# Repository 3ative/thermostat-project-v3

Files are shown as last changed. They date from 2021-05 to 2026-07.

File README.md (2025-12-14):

# ESPHome Thermostat Project V3

Use the "**Code**" button above "**Download ZIP**" to get everything you need.



*Un-ZIP and copy the "**_fonts**" and "**_icons**" folders to your "esphome" folder BEFORE you copy/paste the yaml in to ESPHome*

* 3D Printer files provided are as seen in the tutorial and can be used as a base model for your own 'Front Plate' mounting solutions.

## 2025.2.0 Breaking Change ALERT!!!: (See Comments in the code)
* "Platform": Both the ``esphome:`` and "board" have changed - Now Fixed.
* Changes to how Images are displayed has also beed changed  - Now Fixed.
* Icons and GIFs needed colours inverted  - Now Fixed.

## Please Be Aware:
* Depending on the supplier, SOME OLED displays have the VCC & GND (0v) pins reversed - Be sure to check and adjust your build accordingly.

# Watch the full tutorial here: https://youtu.be/RorDXsYIrnQ

## I have also made a custom PCB for this project. Grab one here: https://www.ebay.co.uk/itm/203570959081




---

<div align="center">

### 💖 Support This Project

Found this useful? Want to say thanks and fuel future creations?

**Your support keeps the creativity flowing!** 🍺✨

<table>
  <tr>
    <td align="center">
      <a href="https://www.buymeacoffee.com/3ative">
        
        <br/>
        <b>☕ Buy me a Coffee</b>
      </a>
    </td>
    <td align="center">
      <a href="https://www.patreon.com/3ative">
        
        <br/>
        <b>💖 Join on Patreon</b>
      </a>
    </td>
  </tr>
</table>

**Every contribution helps bring more awesome projects to life!** 🚀

</div>

---

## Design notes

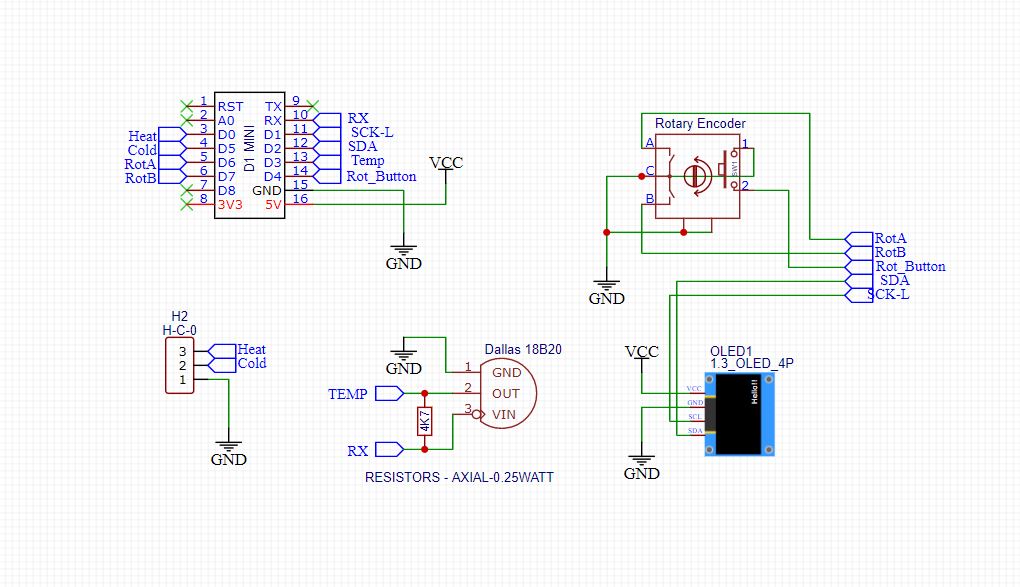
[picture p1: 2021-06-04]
schematic_revised.JPG

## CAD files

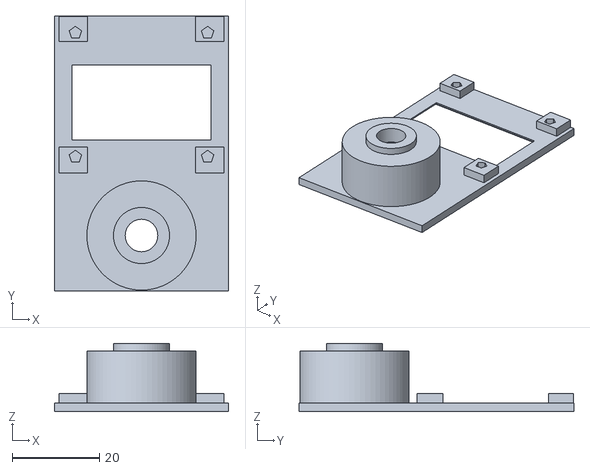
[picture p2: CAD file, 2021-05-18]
3d_printer_files/thermostat_front_plate.stl
40.0 x 63.2 x 15.7

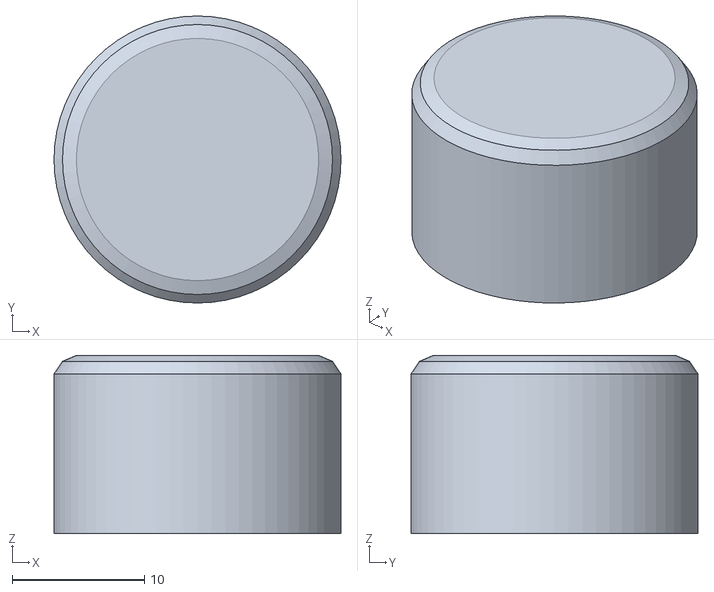
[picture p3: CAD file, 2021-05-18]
3d_printer_files/thermostat_knob.stl
21.7 x 21.7 x 13.5

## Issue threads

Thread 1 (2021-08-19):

Update esphome2021.8.0

twty, 2021-08-19:
Hi,
Esphome 2021.8.0, just replace the hystersis whit 4 new function ''cool_deadband, cool_overrun, heat_deadband and heat_overrun.''
I think you have to update yaml file acording to this change .
regards

3ative, 2021-08-20:
@twty  Thanks for the info. 👍
Please take a look at the YAML code, I updated it. Tested and working here'
Lemma know how you get on.

Closed 2022-02-06.

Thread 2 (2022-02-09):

Thermostat YAML & indication issue

newbie22-guy, 2022-02-09:
I have encountered an issue when trying to compile this project and hope you can assist.

When I used the code supplied I get the following error messages
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

The first issue (lines 72, 73, 76, 77 &78 I resolved with the addition of a # as seen in lines 74 & 75.

The error for line 177 [set_contrast] has been significantly more difficult, and I have not been able to resolve this.
If I move the indentation in or out by  x1 column the indentation error does not repeat but the colon then becomes an issue as the YAML sees it as a mapping value.

I have managed to temporarily bypass this issue, with the deletion of the set_contrast: line (and the associated lines in the YAML).
This allowed me to achieve an upload and some degree of success with the thermostat.

Upon upload I have input the Dallas sensor address, and uncommoned the specified lines as per YouTube tutorial

Within homeassistant I have functionality of both setpoints via the rotary encoder.
This is mirrored on the OLED display, with the graphics.
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

Unfortunately I have no temperature indication either on the OLED or on homeassistant.

3ative, 2022-02-09:
Your line (177) should be this "contrast: 0.4"

As for the others, I see your line numbers are different from my original code. Please post me your full code and I'll take a look.
FYI - To format the code you post, start the block of text with:
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

and end it with:
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

- Those are 'Back checks' and are on the key under the ESc key. :)

newbie22-guy, 2022-02-09:
Thanks for your response.
The coding (from my initial query) I suspect was an old revision, as I re-downloaded the files today and compared them and noted some alterations.
I have now used the latest available YAML.

Based on your reply I now have the original code (now line 196).

This initially gave an error requesting an indentation check, By revising to as below the indentation has been satisfied, but the colon is still posing an issue, I have attached the specific  fault/ issue this highlights.

```yaml
esphome:
  name: thermostat_kitchen
  platform: ESP8266
  board: d1_mini
  on_boot:
    then:
      - lambda: "id(oled_contrast).publish_state(0.4);"
      - switch.turn_off: dallas_power
      - delay: 25s
      - switch.turn_on: dallas_power

substitutions:
  room: Kitchen # Room Name
  entity_heater: input_boolean.tut_thermo_fire_lr
  entity_cooler: input_boolean.tut_thermo_cool_lr
  default_low: "20.0"
  default_hi: "28.0"

wifi:
  ssid: "Deliberately Removed"
  password: "Deliberately Removed"

logger:
  logs:
    climate: none
    sensor: none
    dallas.sensor: none

api:
ota:

i2c:

switch:
  - platform: gpio
    id: dallas_power
    pin:
      number: GPIO03

  - platform: template
    id: heat_cool

    optimistic: true
  - platform: gpio
    id: relay_heater
    pin: D0
    inverted: true
  - platform: gpio
    id: relay_cooler
    pin: D5
    inverted: true
  - platform: template
    id: brightness
    optimistic: true

binary_sensor:
  - platform: template
    id: fire
  - platform: template
    id: cool

  - platform: gpio
    id: button
    pin:
      number: D4
      inverted: true
    on_press:
      then:
        - switch.toggle: heat_cool
    on_click:
      - min_length: 1000ms
        max_length: 20000ms
        then:
          - switch.toggle: brightness

dallas:
  pin: D3
  update_interval: 3s

climate:
  - platform: thermostat
    min_cooling_off_time: 0s
    min_cooling_run_time: 0s
    # min_fanning_off_time: 0s
    # min_fanning_run_time: 0s
    min_heating_off_time: 0s
    min_heating_run_time: 0s
    min_idle_time: 0s
    visual:
      min_temperature: 15 °C
      max_temperature: 30 °C
    name: "${room} Thermostat"
    id: this_thermostat
    sensor: internal_temperature

    default_target_temperature_low: ${default_low}
    default_target_temperature_high: ${default_hi}

    cool_action:
      - switch.turn_on: relay_cooler
      - lambda: id(cool).publish_state(true);
      - homeassistant.service:
          service: homeassistant.turn_on
          data:
            entity_id: ${entity_cooler}

    heat_action:
      - switch.turn_on: relay_heater
      - lambda: id(fire).publish_state(true);
      - homeassistant.service:
          service: homeassistant.turn_on
          data:
            entity_id: ${entity_heater}

    idle_action:
      - switch.turn_off: relay_cooler
      - switch.turn_off: relay_heater
      - lambda: id(cool).publish_state(false);
      - lambda: id(fire).publish_state(false);
      - homeassistant.service:
          service: homeassistant.turn_off
          data:
            entity_id: ${entity_cooler}
      - homeassistant.service:
          service: homeassistant.turn_off
          data:
            entity_id: ${entity_heater}

sensor:
  - platform: template
    id: oled_contrast

  - platform: dallas
    id: internal_temperature
    address: 0x28ff6401be7b6410

  - platform: rotary_encoder
    id: encoder
    pin_a:
      number: D6
      mode: INPUT_PULLUP
    pin_b:
      number: D7
      mode: INPUT_PULLUP
    on_clockwise:
      - if:
          condition:
            switch.is_on: brightness
          then:
            - sensor.template.publish:
                id: oled_contrast
                state: !lambda "return id(oled_contrast).state + 0.01;"
            - lambda: |-
                id(oled1).set_contrast( id(oled_contrast).state );
          else:
            - if:
                condition:
                  switch.is_on: heat_cool
                then:
                  - climate.control:
                      id: this_thermostat
                      target_temperature_high: !lambda "return id(this_thermostat).target_temperature_high + 0.5;"
                else:
                  - climate.control:
                      id: this_thermostat
                      target_temperature_low: !lambda "return id(this_thermostat).target_temperature_low + 0.5;"

    on_anticlockwise:
      then:
        - if:
            condition:
              switch.is_on: brightness
            then:
              - sensor.template.publish:
                  id: oled_contrast
                  state: !lambda "return id(oled_contrast).state - 0.01;"
              - lambda: |-
                  id(oled1).set_contrast( id(oled_contrast).state);
            else:
              - if:
                  condition:
                    switch.is_on: heat_cool
                  then:
                    - climate.control:
                        id: this_thermostat
                        target_temperature_high: !lambda "return id(this_thermostat).target_temperature_high - 0.5;"
                  else:
                    - climate.control:
                        id: this_thermostat
                        target_temperature_low: !lambda "return id(this_thermostat).target_temperature_low - 0.5;"
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
3ative, 2022-02-11:
Try this,
Wire the Dallas sensor, on its's own to a D1 Mini and flash only with the code example here
https://esphome.io/components/sensor/dallas.html

If it still doesn't work, I guess it's your sensors.

newbie22-guy, 2022-02-11:
I was beginning to suspect likewise, but I was dubious that I would have so many faulty sensors.

Initially I built the DS_Fake_Tester by electrical-pro (https://github.com/electrical-pro/Ds_Fake_Tester)
This proved to be quite encouraging as all the sensors indicated as being genuine, and displayed readings.

I've had another play with these this morning.
Using the guide below
https://everythingsmarthome.co.uk/howto/building-a-temperature-sensors-for-home-assistant-wemos-d1-mini-with-ds18b20-build-guide/

Initially I built this up on breadboard for simplicity of substituting sensors & D1's.
I have successfully managed to gain temperature readings from multiple sensors.
I have also managed this with a number of D1 mini's.

I amended the code from the example to increase the refresh rate to 3 sec, and alternated the GPIO pin between pin 3 & 4 (to confirm no issue with either pin)
Both worked as expected and provided updates every 3 secs, with no issue over the period of 15mins.

I  have since remounted the D1 mini back to the PCB (I've used pin sockets for ease)
Reverting the GPIO for the Dallas to GPIO3, as this conforms to the PCB track layout.
Via jumper wires to the ds18b20 solder pads, the temperature readings operate as expected.
Obviously the OLED and the Rotary encoder are out of the loop at this point.
With the ds18b20 legs placed through the relevant solder pads, running the above code the setup has run for about 1 hour now faultlessly
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

3ative, 2022-02-11:
# OMG You are using one of my PCBs!!!

I wish you would have said from the outset.... the Dallas Sensor 'Label' is reversed on those! You have to mount it on the underside.
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

## I'm so sorry - I'm sure I emailed everybody that brought them.

newbie22-guy, 2022-02-11:
Ah sorry my bad, I should have been more accurate in my explanation.

I had noticed that and that is why the photo only shows the ds18B20 legs visible at the solder pads.
(They are just sat in place at the moment)

This setup using this mornings code operates (minus display etc).

If I again revert to the original code the same scenario persists of no temp display on the OLED or home assistant.

The purpose (in my mind) of this test was to confirm that the data pin GPIO3 was able to receive the signal via the PCB.
In the thought of a bad contact, high resistance on x1 line etc

This seems to have proven the board healthy, and the ds18b20's are good too.

I'm not now sure where this is pointing?!?

Can I ask what supply you use for your examples?
As previously mentioned I have tried a few USB supplies, and now wonder if they aren't able to supply the required current for both the D1 &  the OLED, although this wouldn't explain the non operation if the OLED is disconnected.

3ative, 2022-02-11:
**Software wise, we've sorted that**
**Component wise, all's been verified**
**PSU, shouldn't have been an issue anyway** - _(still was worth the check thou - You never know)_

_... and you've previously stated you've checked for shorts, bad connections, etc._

There's nothing else to check... We've covered everything I would have done in the same situation.

:(

newbie22-guy, 2022-02-11:
Ha yeah that's where I've ended up too.

I'll try another full component assembly this evening, purely on breadboard as it makes it quicker & easier to switch components etc

It's really confusing the hell outta me

newbie22-guy, 2022-02-11:
Well I have had some success at last 😁

I tried rebuilding the circuit on breadboard this evening, with no joy, exactly the same results as previously.

In a final vain attempt I put the D1 back on the PCB, and after a couple of reboots it fired into life.

Fully functioning local OLED & home assistant indication.
Graphics alter if temp varied to setpoints, the works.

I am completely bamboozled as to how this came about, but more than a little chuffed at the same time lol

Just thought I would offer an update, and say thanks again for your assistance, it's massively appreciated

3ative, 2022-02-12:
That's great News!... and Phew 👍

YAY you - Coz, I'd totally ran out of ideas of what to check.

Thanks for letting me know - If you do find out what it was, please do let me know.

Closed 2022-02-09.

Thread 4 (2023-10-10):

help

Pokornypetr, 2023-10-10:
Hi, I tried your project. nice but i have a problem After drying, item L can be set after pressing the encoder button, then item H, nothing happens when the button is pressed for a longer time, nothing happens when the button is pressed again for a short time, and the contrast of the LCD cannot be set, which I would not mind, but unfortunately, the main thing is that you cannot return to item L which in my opinion is a bigger problem, how to solve it please?

3ative, 2023-10-10:
There's no problem with either the hardware or my code - I'm currently running same here without issue.

- Check your setup and code - Either something is wrong or you did something wrong.
- Also, make sure you are using the latest ESPHome update(s)

Pokornypetr, 2023-10-11:
Hello, I have no idea why it doesn't work, I'm doing everything on a different board: https://www.aliexpress.com/item/1005003268288997.html?spm=a2g0o.order_list.order_list_main.105.2af41802uiELK1
with 2 relays but connected the same button works on changes from L to H but not back. The version of esphome is up-to-date, as well as everything, I also checked the program code, it is the same, I just changed the name of the room and removed the humidity sensor from the lcd

3ative, 2023-10-11:
Well if you don't know why it's not working... I don't know how you expect me to!

If you want to pay for my flight and Hotel, I'll have a go at fixing it for you. :)

Pokornypetr, 2023-10-11:
I was thinking of some advice on what to look for. I know that when I tried version 2 a few months ago, everything worked, but I just can't do it in this new version. do you have the code of the initial versions stored somewhere?

3ative, 2023-10-11:
I can't debug you code if it's not formatted properly - what you've shared there is not YAML.

The code hasn't changed for over 10 months, and even that was a small change to the "DALLAS Sensor Log".
 - So it can't be that.

 Things to look for:
 - Check your code
 - Check your components
 - Check your wiring

 I hope you can appreciate there's not much I can do from here, as I can't see what you've done or how you've done it. Obviously the project works. So again, you've either done something different or used something different.

Pokornypetr, 2023-10-11:
Svůjkod jsem poslal I also have the same connection with HW. I have no doubt that everything works for you jenne, I can find out why it doesn't work for me :D. as I said the first time I press the button on the encoder the setting status changes from L to H the arrow turns on the lcd and I can set the H value when I press the encoder button again nothing happens. Nothing happens when the button is pressed for a long time.

3ative, 2023-10-11:
> Svůjkod jsem poslal
No, you sent text. I can't help if it's not YAML (original) formatted.

> I also have the same connection with HW.
Maybe... but you're not using the same D1 Mini and you haven't told me what other HW you've changed too.

> as I said the first time I press the button on the encoder the setting status changes from L to H the arrow turns on the lcd and I can set the H value when I press the encoder button again nothing happens. Nothing happens when the button is pressed for a long time.
As I said, "Check your components", maybe your button is faulty?

Closed 2023-10-11.

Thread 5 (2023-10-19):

hello

Pokornypetr, 2023-10-19:
hello, as I indicated in the previous problem, switching between L and H with the button and setting the backlight did not work for me, everything was solved by writing **Input_pullaup** :`- platform: gpio
    id: button
    pin:
      number: D4
      mode: INPUT_PULLUP
      inverted: true
    on_press:
      then:
        - switch.toggle: heat_cool`

3ative, 2023-10-19:
I guess it was a hardware issue then.
Cool you found it, there's no way I could have from here.

Closed 2023-10-19.

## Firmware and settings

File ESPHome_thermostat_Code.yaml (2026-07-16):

substitutions:
  room: Kitchen # Room Name
  entity_heater: input_boolean.tut_thermo_fire    ### Change for your 'Heating' Entity
  entity_cooler: input_boolean.tut_thermo_cool    ### Change for your 'Cooling' Entity
  default_low: "20"
  default_hi: "28"

######### Note the Changes in these Sections ##########
esphome:
  name: "thermostat-kitchen"
  on_boot:
    priority: -100.0
    then:
      - switch.turn_on: dallas_power
      - lambda: "id(oled_contrast).publish_state(0.4);"

esp8266:
  board: d1_mini
########################################################

wifi:
  networks:
    - ssid: !secret wifi_ssid
      password: !secret wifi_password

logger:
  logs:
    climate: none
    sensor: none
    # dallas.sensor: none

api:
ota:
  platform: esphome

i2c:
  frequency: 400kHz

switch:
  - platform: gpio
    id: dallas_power
    name: "Dallas Power"
    pin:
      number: GPIO03

  - platform: template
    id: heat_cool

    optimistic: true
  - platform: gpio
    id: relay_heater
    pin: D0
    inverted: true
  - platform: gpio
    id: relay_cooler
    pin: D5
    inverted: true
  - platform: template
    id: brightness
    optimistic: true

binary_sensor:
  - platform: template
    id: fire
  - platform: template
    id: cool

  - platform: gpio
    id: button
    pin:
      number: D4
      inverted: true
    on_press:
      then:
        - switch.toggle: heat_cool
    on_click:
      - min_length: 1000ms
        max_length: 20000ms
        then:
          - switch.toggle: brightness

climate:
  - platform: thermostat
    min_cooling_off_time: 0s
    min_cooling_run_time: 0s
    min_heating_off_time: 0s
    min_heating_run_time: 0s
    min_idle_time: 0s
    visual:
      min_temperature: 15 °C
      max_temperature: 30 °C
    name: "${room} Thermostat"
    id: this_thermostat
    sensor: internal_temperature

### Updated for ESPHome v2022.10.0 Onwards
    default_preset: Home                      ### NEW! Use this to set Preset
    # on_boot_restore_from: memory            ### Use this to "Restore From Memeory" (A Saved State) OR...
    on_boot_restore_from: default_preset      ### Use this to set Preset to start on every Boot
    preset:
      - name: Home
        default_target_temperature_low: $default_low
        default_target_temperature_high: $default_hi
        mode: HEAT_COOL                       ### Changed from "auto" to "HEAT_COOL"
###########################################

##### Added to fix for Heat Cool Mode #####
    heat_cool_mode:
      then:
        - lambda: |-
            // Do nothing
###########################################

    cool_action:
      - switch.turn_on: relay_cooler
      - lambda: id(cool).publish_state(true);
      - homeassistant.service:
          service: homeassistant.turn_on
          data:
            entity_id: $entity_cooler

    heat_action:
      - switch.turn_on: relay_heater
      - lambda: id(fire).publish_state(true);
      - homeassistant.service:
          service: homeassistant.turn_on
          data:
            entity_id: $entity_heater

    idle_action:
      - switch.turn_off: relay_cooler
      - switch.turn_off: relay_heater
      - lambda: id(cool).publish_state(false);
      - lambda: id(fire).publish_state(false);
      - homeassistant.service:
          service: homeassistant.turn_off
          data:
            entity_id: $entity_cooler
      - homeassistant.service:
          service: homeassistant.turn_off
          data:
            entity_id: $entity_heater

one_wire:
  - platform: gpio
    pin: D3
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

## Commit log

2021-05-18 Front Plates parts for 3D Printing
    [thermostat_front_plate.stl, thermostat_knob.stl]
2021-05-21 Circuit schematic
2021-06-22 OLED Pin warning
2021-08-19 Additional code added to fix 2021.8.0 change
    [ESPHome_thermostat_Code.yaml]
2022-10-12 Updated Code - Fix OLED & DALLAS
    [ESPHome_thermostat_Code.yaml]
2022-10-12 OLED + DALLAS Fix
    [ESPHome_thermostat_Code.yaml]
2022-12-06 Commented out DALLAS Sensor Log
